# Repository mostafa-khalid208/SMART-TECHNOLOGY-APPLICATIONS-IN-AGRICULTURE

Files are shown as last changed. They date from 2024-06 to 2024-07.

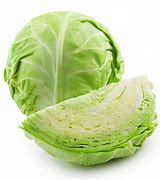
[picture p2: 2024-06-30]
APK & Code/smart_irrigation/smart_irrigation/assets/images/OIP_(1)ht.jpg

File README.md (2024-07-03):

# SMART-TECHNOLOGY-APPLICATIONS-IN-AGRICULTURE

Mobile application interface

In the ever-changing world of farming, smart agricultural systems have emerged as game-changers, using fancy tech to tackle big challenges like feeding a growing global population while being kind to the planet. This graduation project book is your go-to guide to understand and dive deep into these innovative farming solutions.

Create Login

Additional pages in the project

[Create & Login Account (Practical application ) ]( https://youtu.be/F7y6CJShDI8 )

We'll take you on a tour of the cool tech behind smart agriculture, from building mobile apps with Flutter to using AI for making smart decisions and managing data in the Cloud. You'll get hands-on with hardware like ESP32 and IoT devices, learning how they collect data and automate tasks on the farm.

Diagram_1

Diagram_2

Sensor reading page

[Sensors & Microcontroller ( Practical application ) ]( https://youtu.be/qTxyqkGCsHM )

But it's not all theory—get ready to roll up your sleeves and put these ideas into action. We'll show you how smart irrigation systems work, using sensors and AI to water crops just right. Plus, you'll learn how AI can spot plant diseases early, helping farmers protect their harvests and boost productivity.

Chat page with pictures with artificial intelligence

Chat page with artificial intelligence

[Artificial intelligence (AI) Chat & Image (Practical application ) ]( https://youtu.be/XoeHMlaQuq4 )

[Full in-app AI experience ]( https://youtube.com/shorts/PL40P1889J8 )

We won't just stop at building cool stuff; We'll also talk about how to measure success. We'll look at how these systems increase crop yields, save resources, and make farming more sustainable. And we'll dive into how they're making a real difference in food security and protecting our environment.

But we're not done yet—get ready to peer into the future of farming. We'll explore exciting new technology like 5G, fog computing, and the Internet of Everything, and how they'll shape the farms of tomorrow. And we'll discuss how renewable energy, virtual reality, and more will play a role in making farming even smarter.

FireBase(FireStore)

Solar System

[Firebase & FireStore (Practical application ) ]( https://youtu.be/0Hn9pTRTNbc )

By bringing together the latest research and hands-on practices, this project is your ticket to understanding and creating the future of farming. Whether you're a student looking to dive into smart agriculture or a researcher pushing the boundaries of what's possible, this project is your roadmap to a greener, more efficient future in farming.

the graduation project

[Smart Irrigation System (Final practical application of the graduation project ) ]( https://youtube.com/shorts/qQlA1rqxmsU?feature=shared )

[Full mobile app experience ]( https://youtu.be/DmjhwGzqkdA?feature=shared )

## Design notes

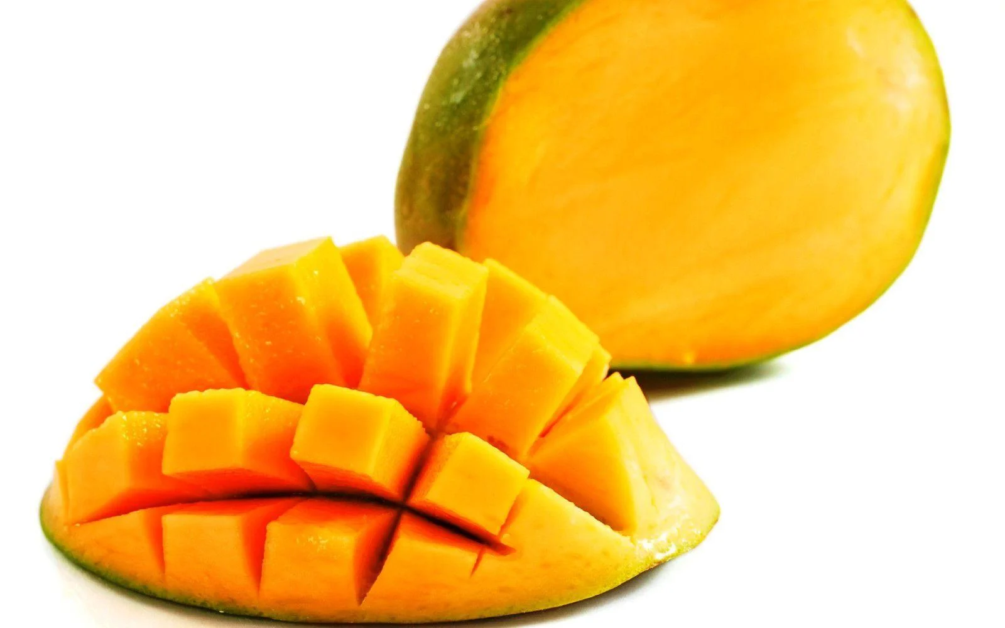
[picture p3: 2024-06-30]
APK & Code/smart_irrigation/smart_irrigation/assets/images/efef.webp

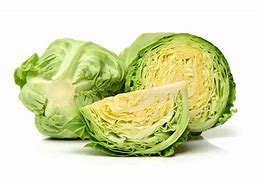
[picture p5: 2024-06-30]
APK & Code/smart_irrigation/smart_irrigation/assets/images/OIP_(1)gfg.jpg

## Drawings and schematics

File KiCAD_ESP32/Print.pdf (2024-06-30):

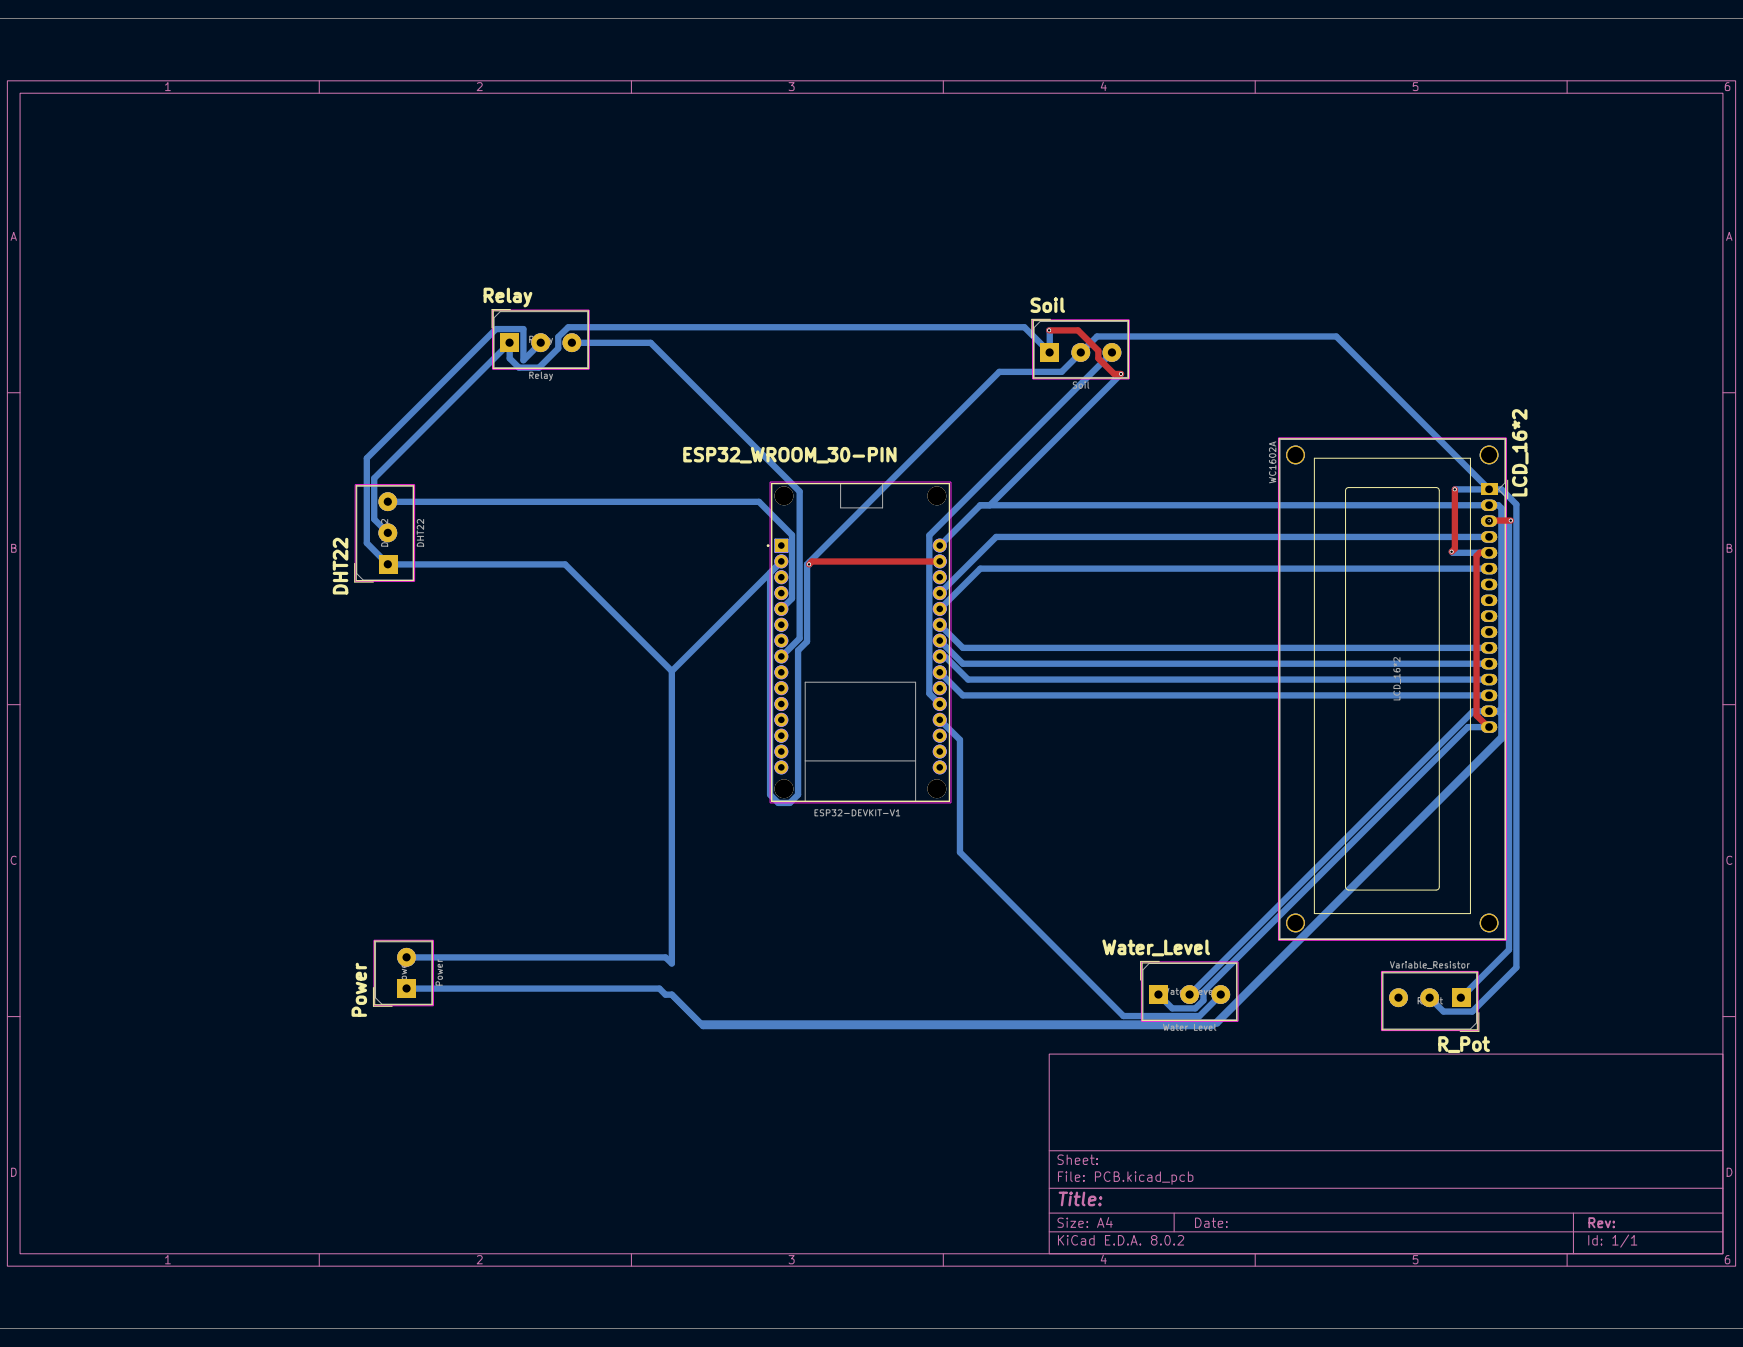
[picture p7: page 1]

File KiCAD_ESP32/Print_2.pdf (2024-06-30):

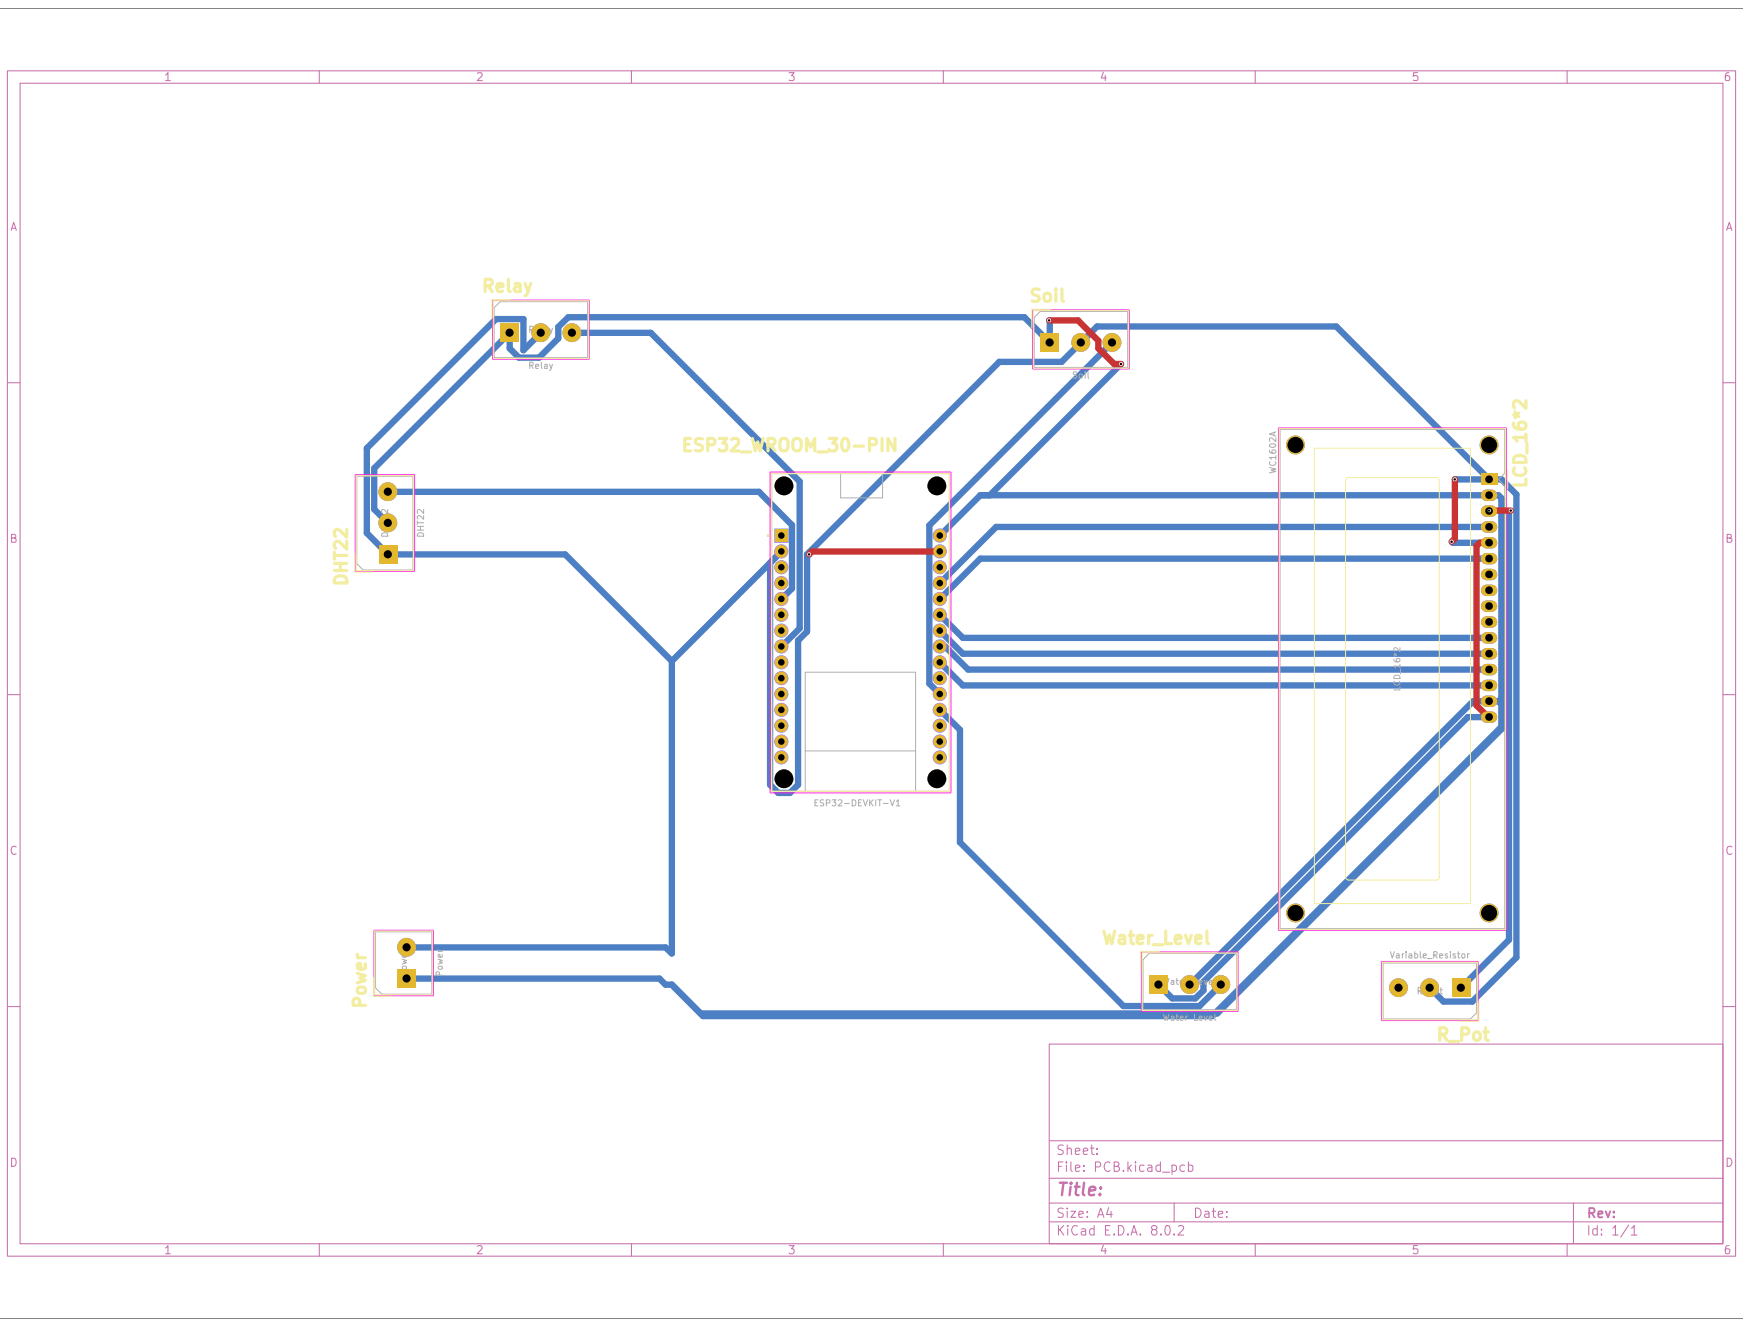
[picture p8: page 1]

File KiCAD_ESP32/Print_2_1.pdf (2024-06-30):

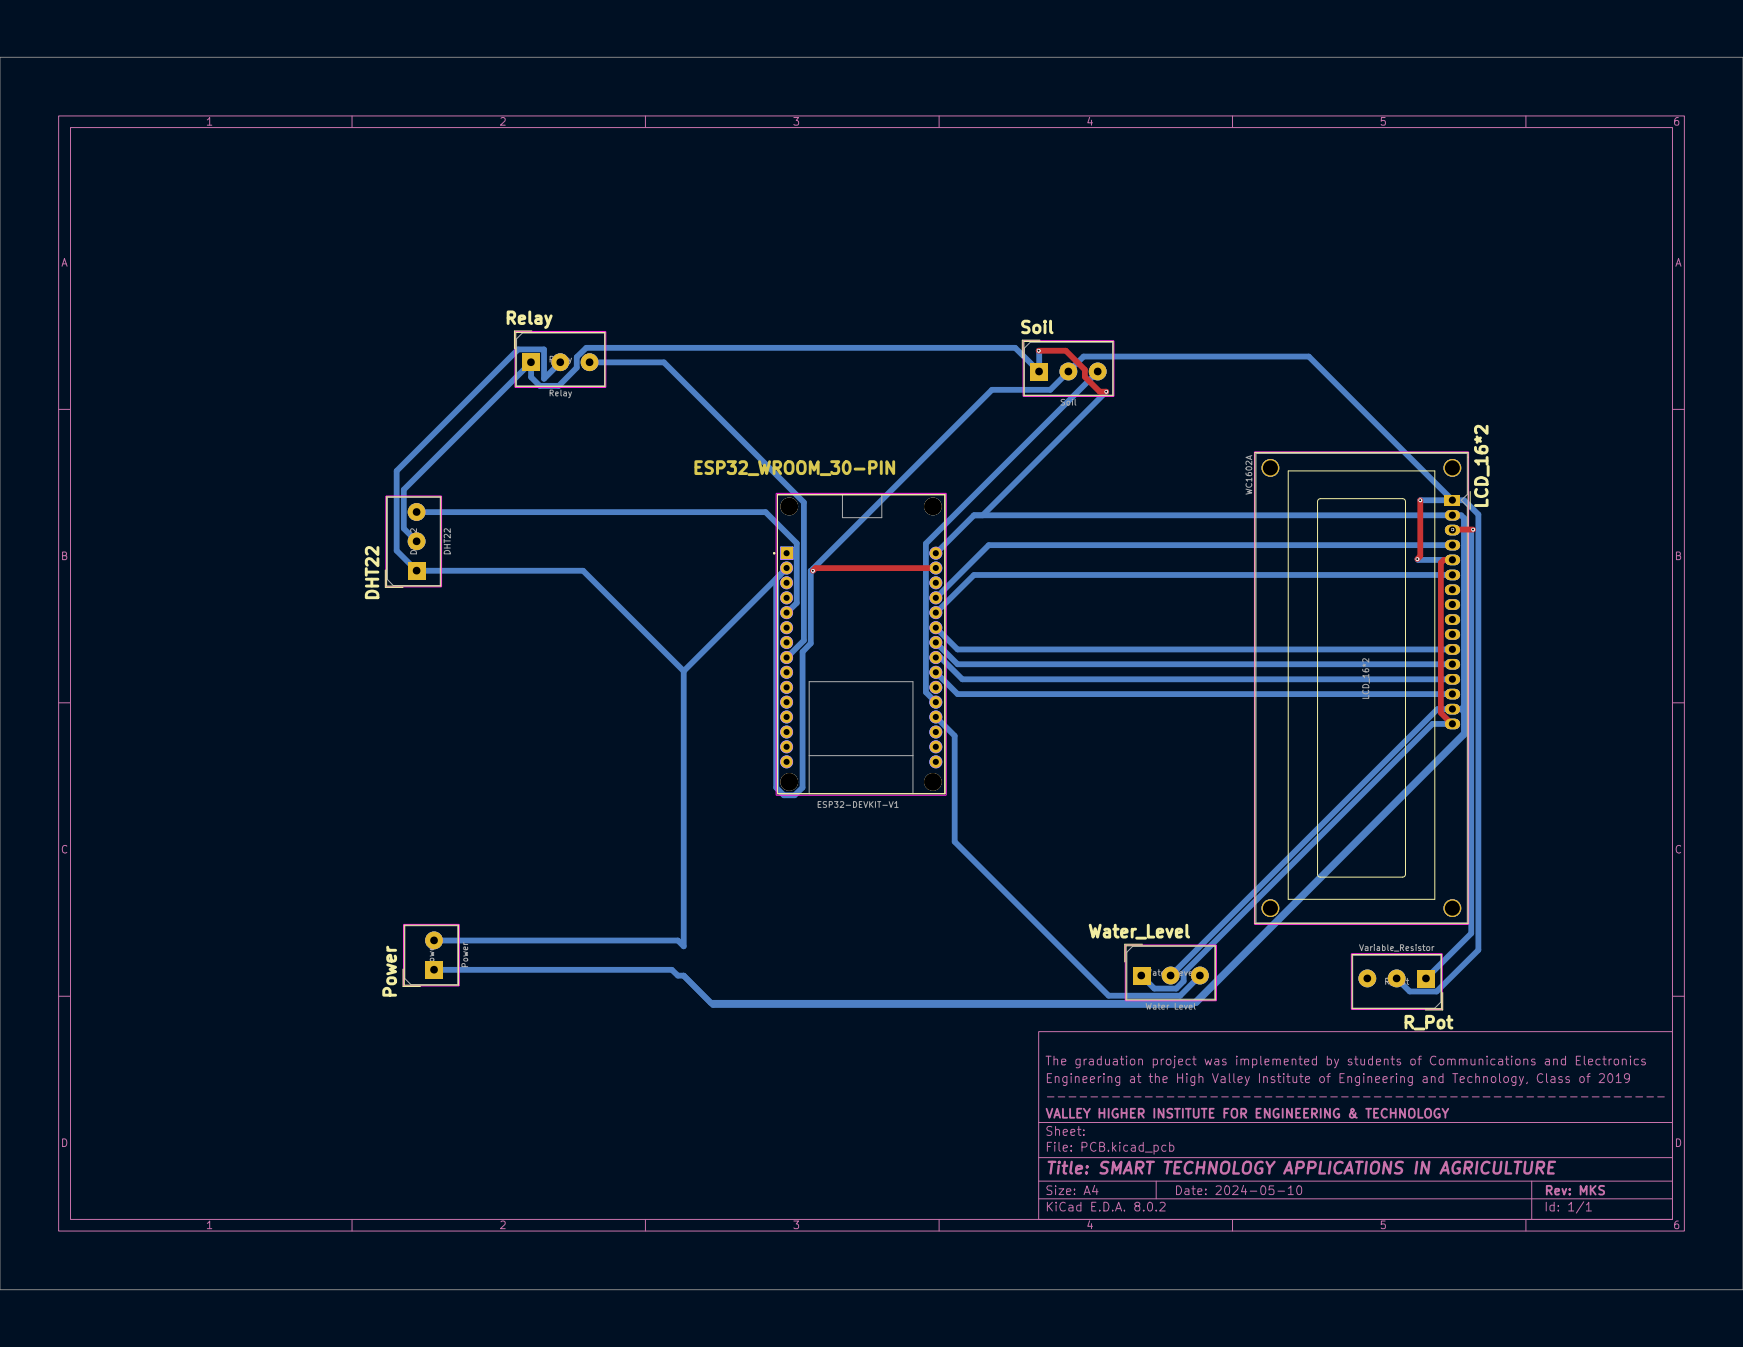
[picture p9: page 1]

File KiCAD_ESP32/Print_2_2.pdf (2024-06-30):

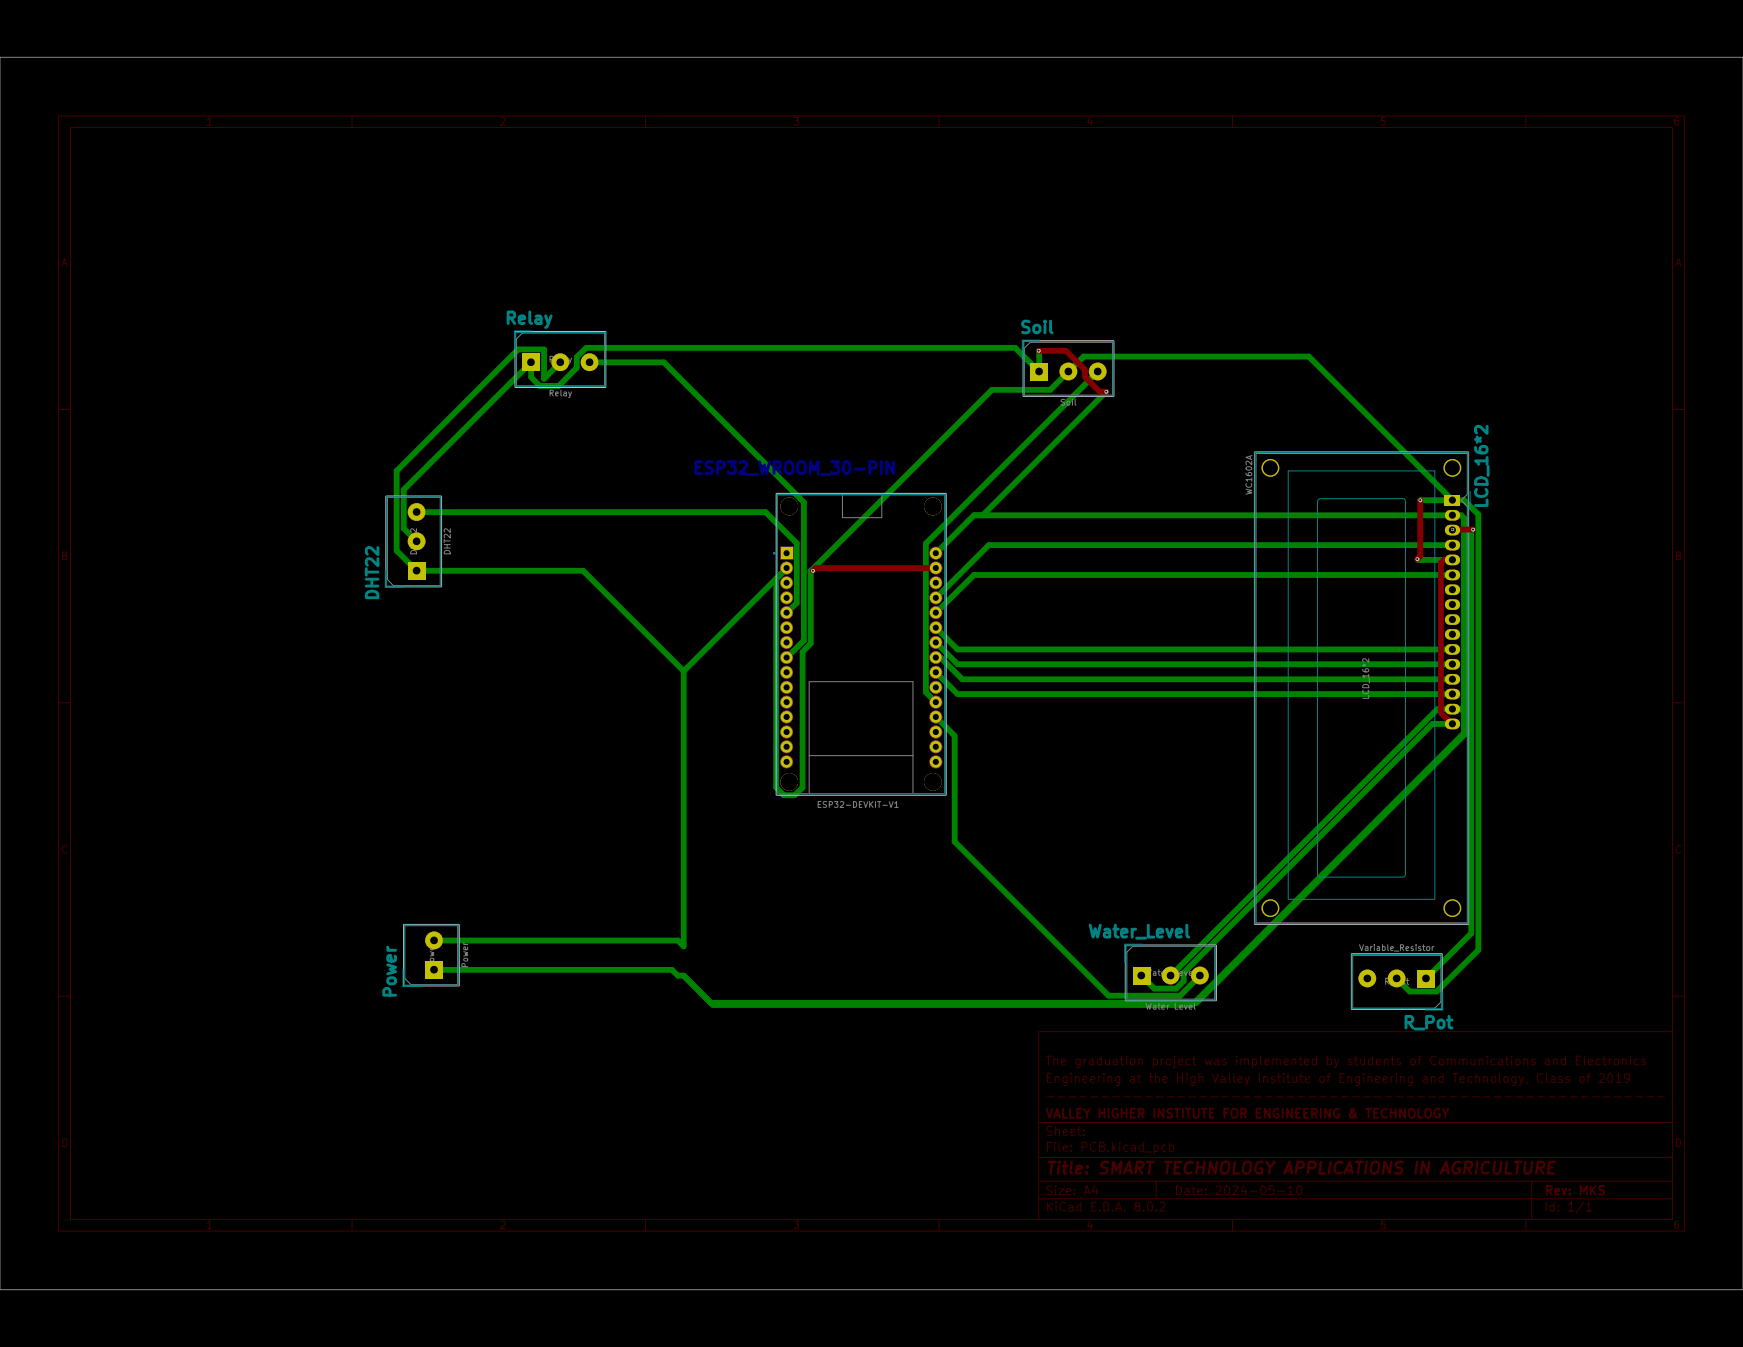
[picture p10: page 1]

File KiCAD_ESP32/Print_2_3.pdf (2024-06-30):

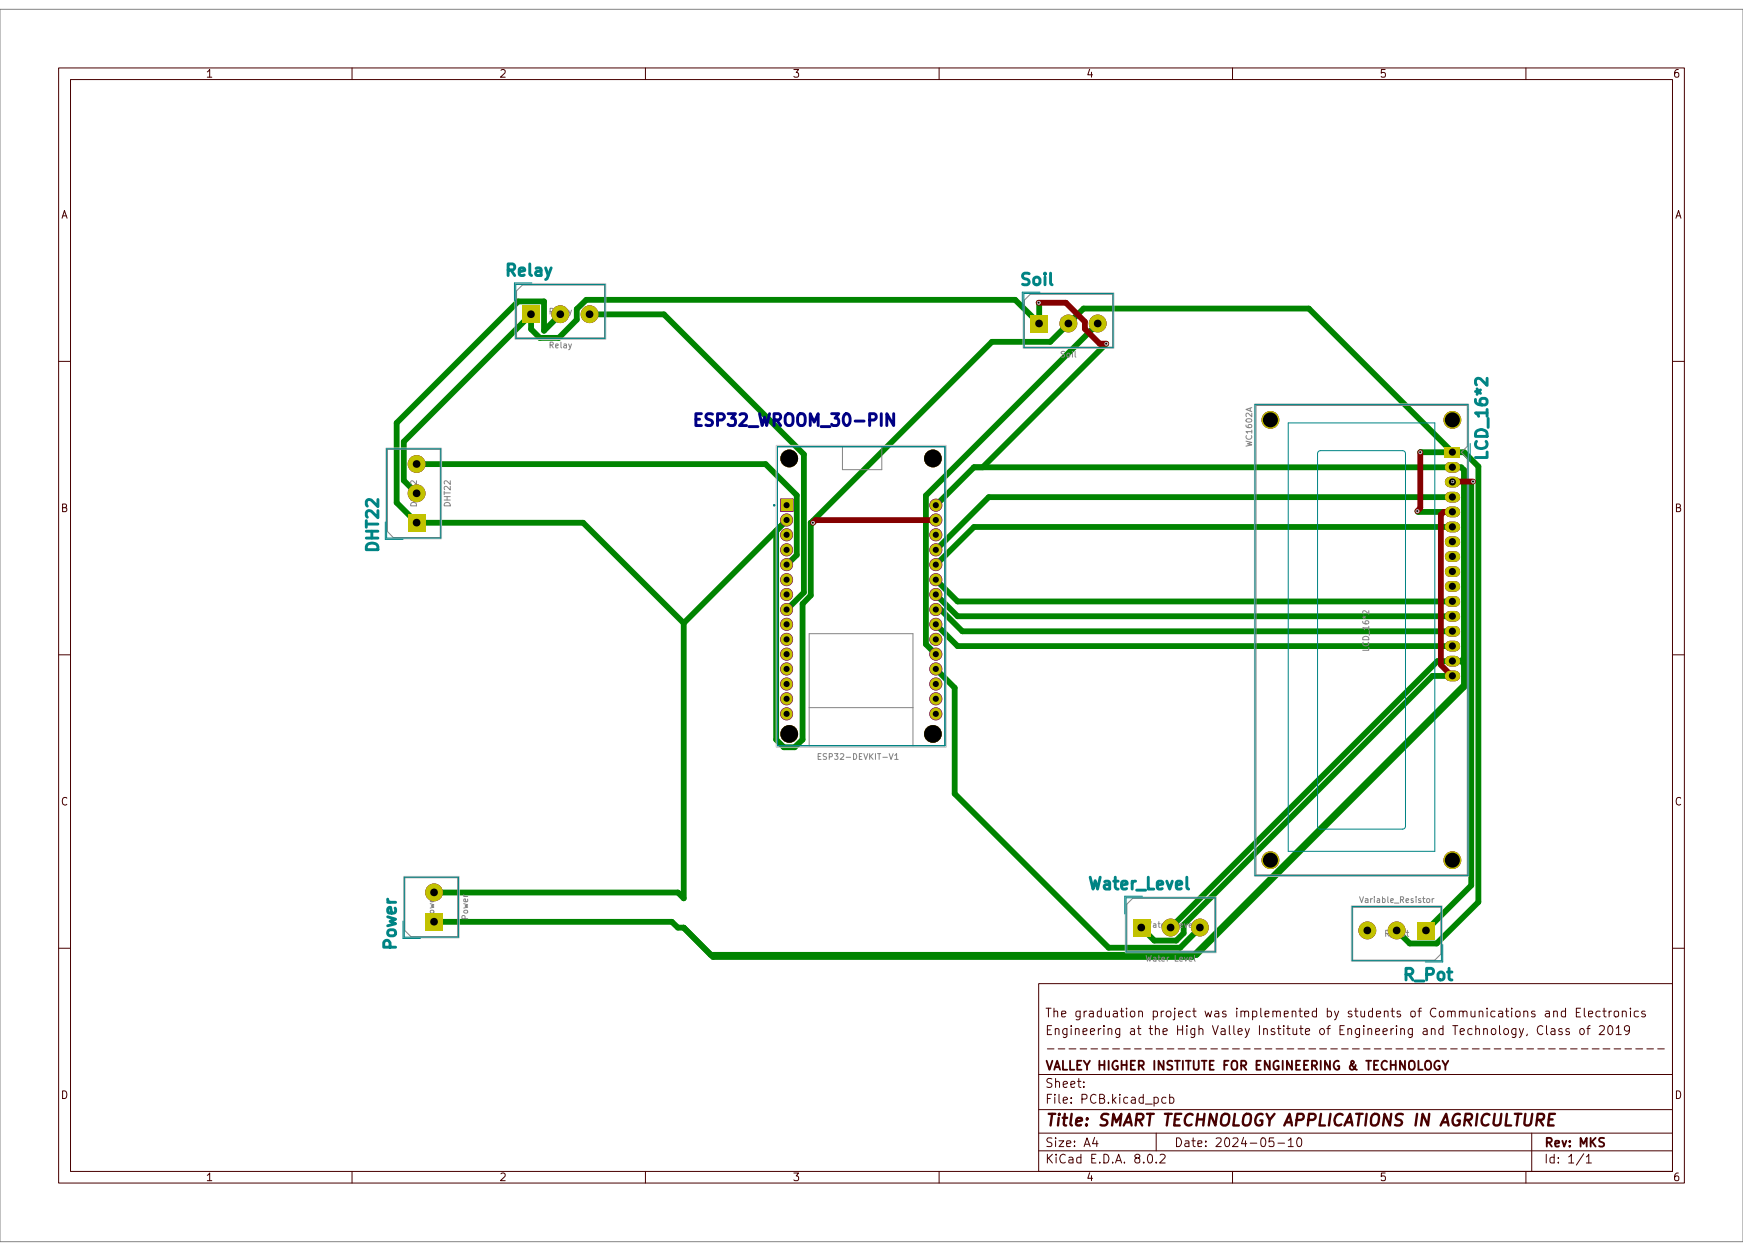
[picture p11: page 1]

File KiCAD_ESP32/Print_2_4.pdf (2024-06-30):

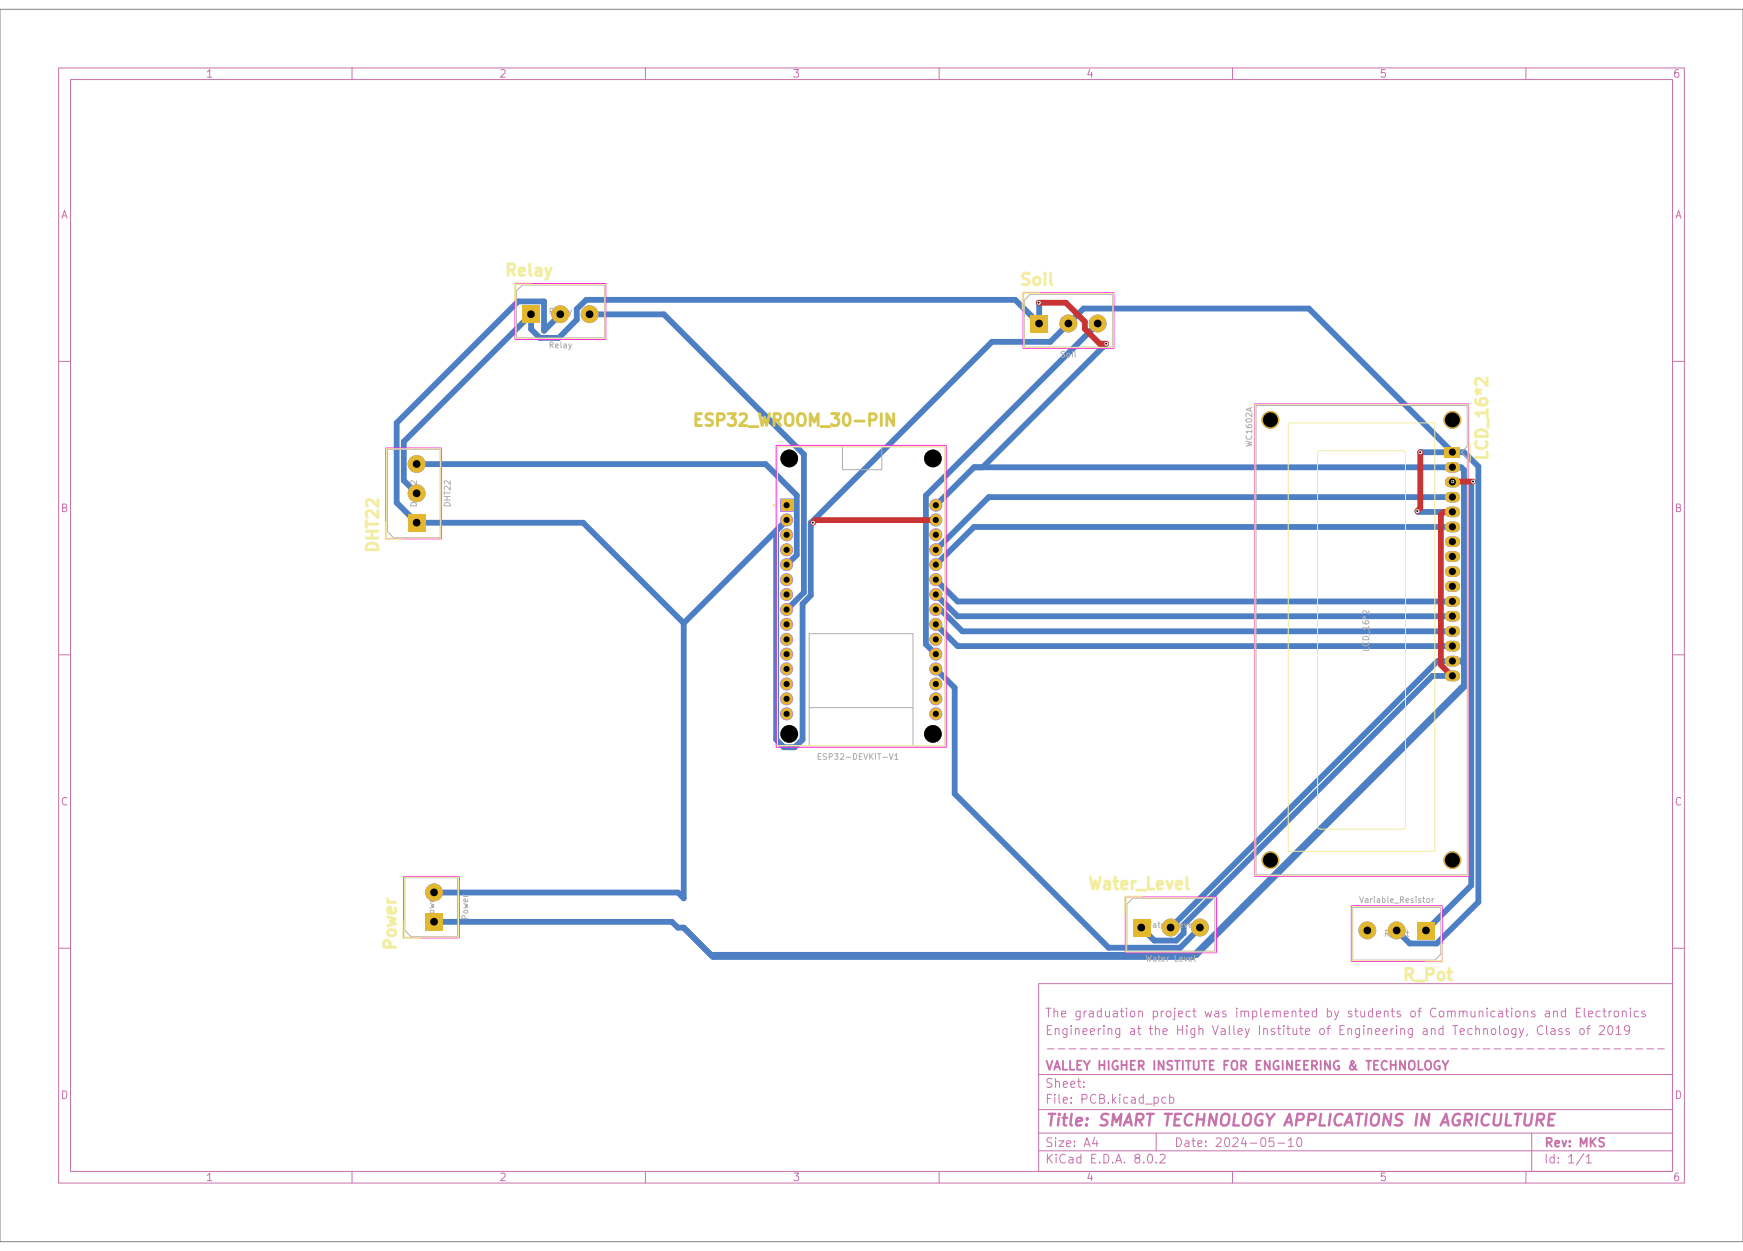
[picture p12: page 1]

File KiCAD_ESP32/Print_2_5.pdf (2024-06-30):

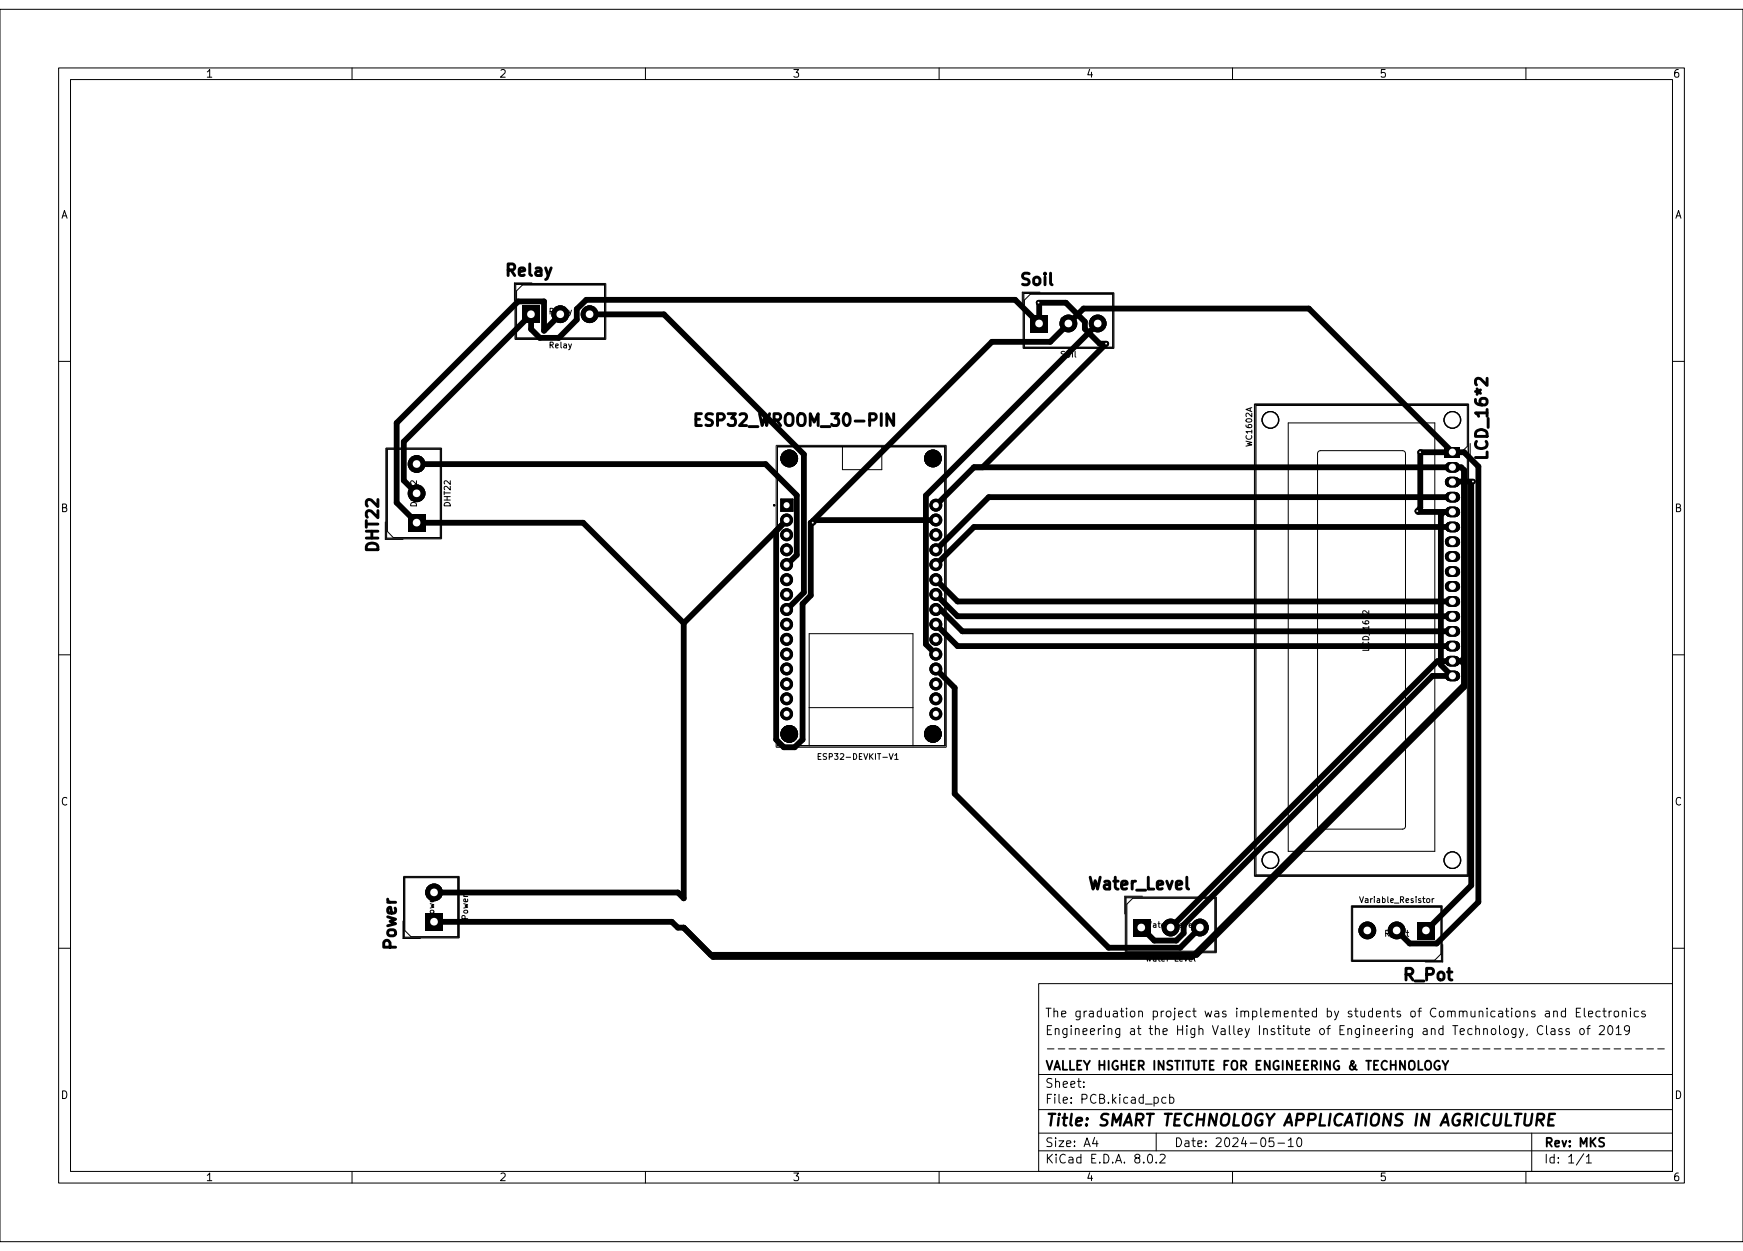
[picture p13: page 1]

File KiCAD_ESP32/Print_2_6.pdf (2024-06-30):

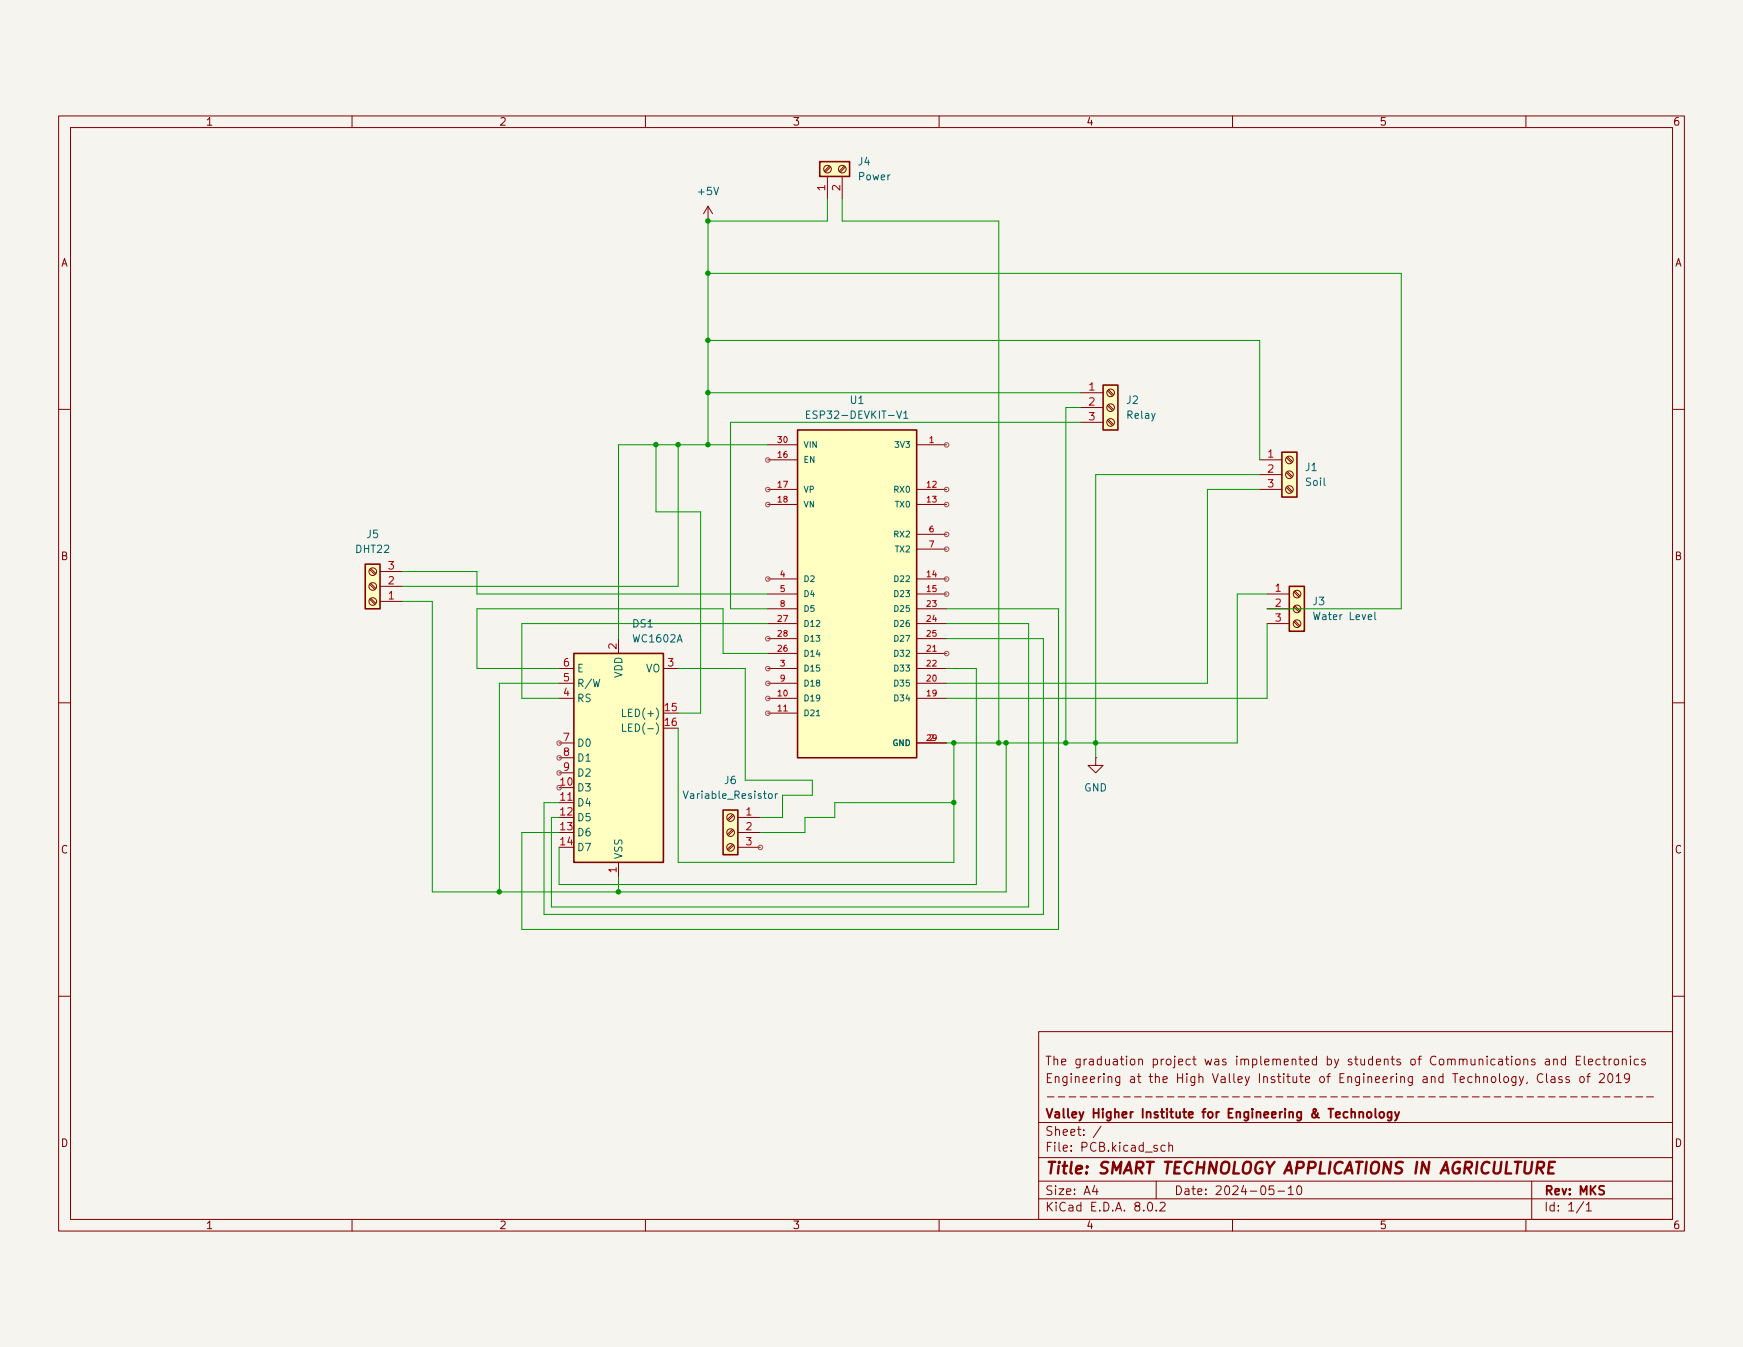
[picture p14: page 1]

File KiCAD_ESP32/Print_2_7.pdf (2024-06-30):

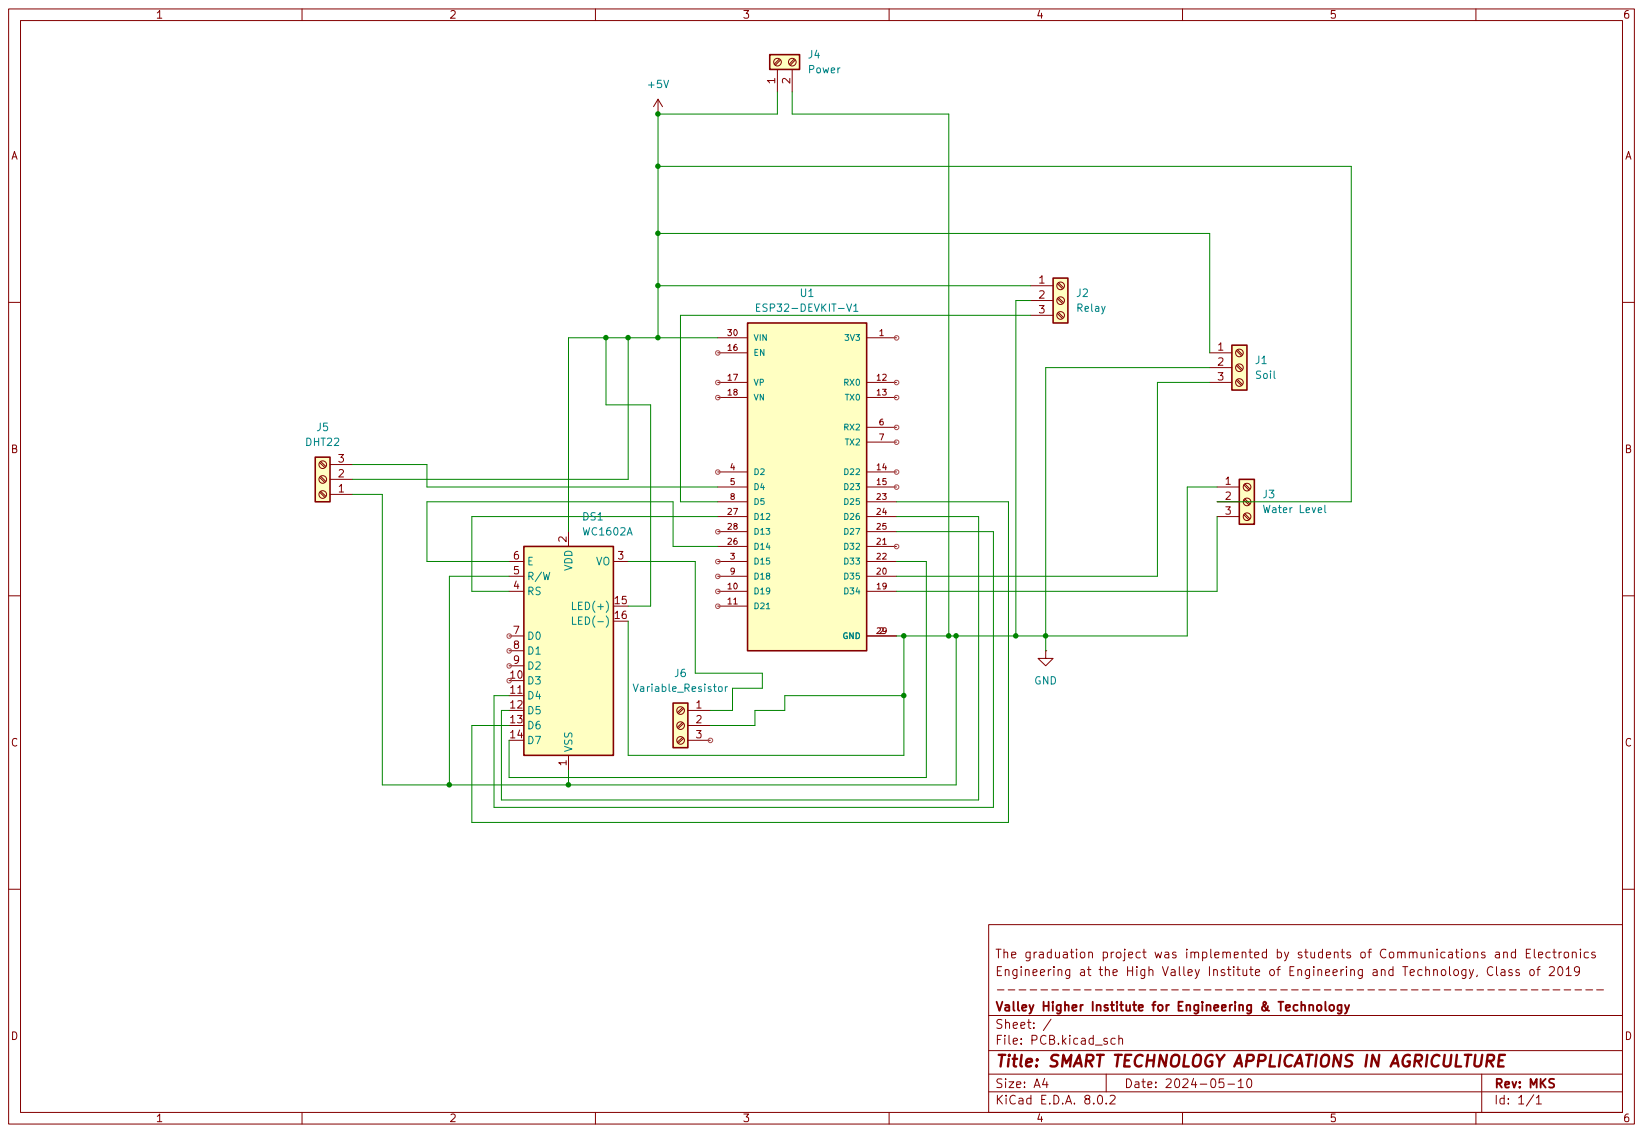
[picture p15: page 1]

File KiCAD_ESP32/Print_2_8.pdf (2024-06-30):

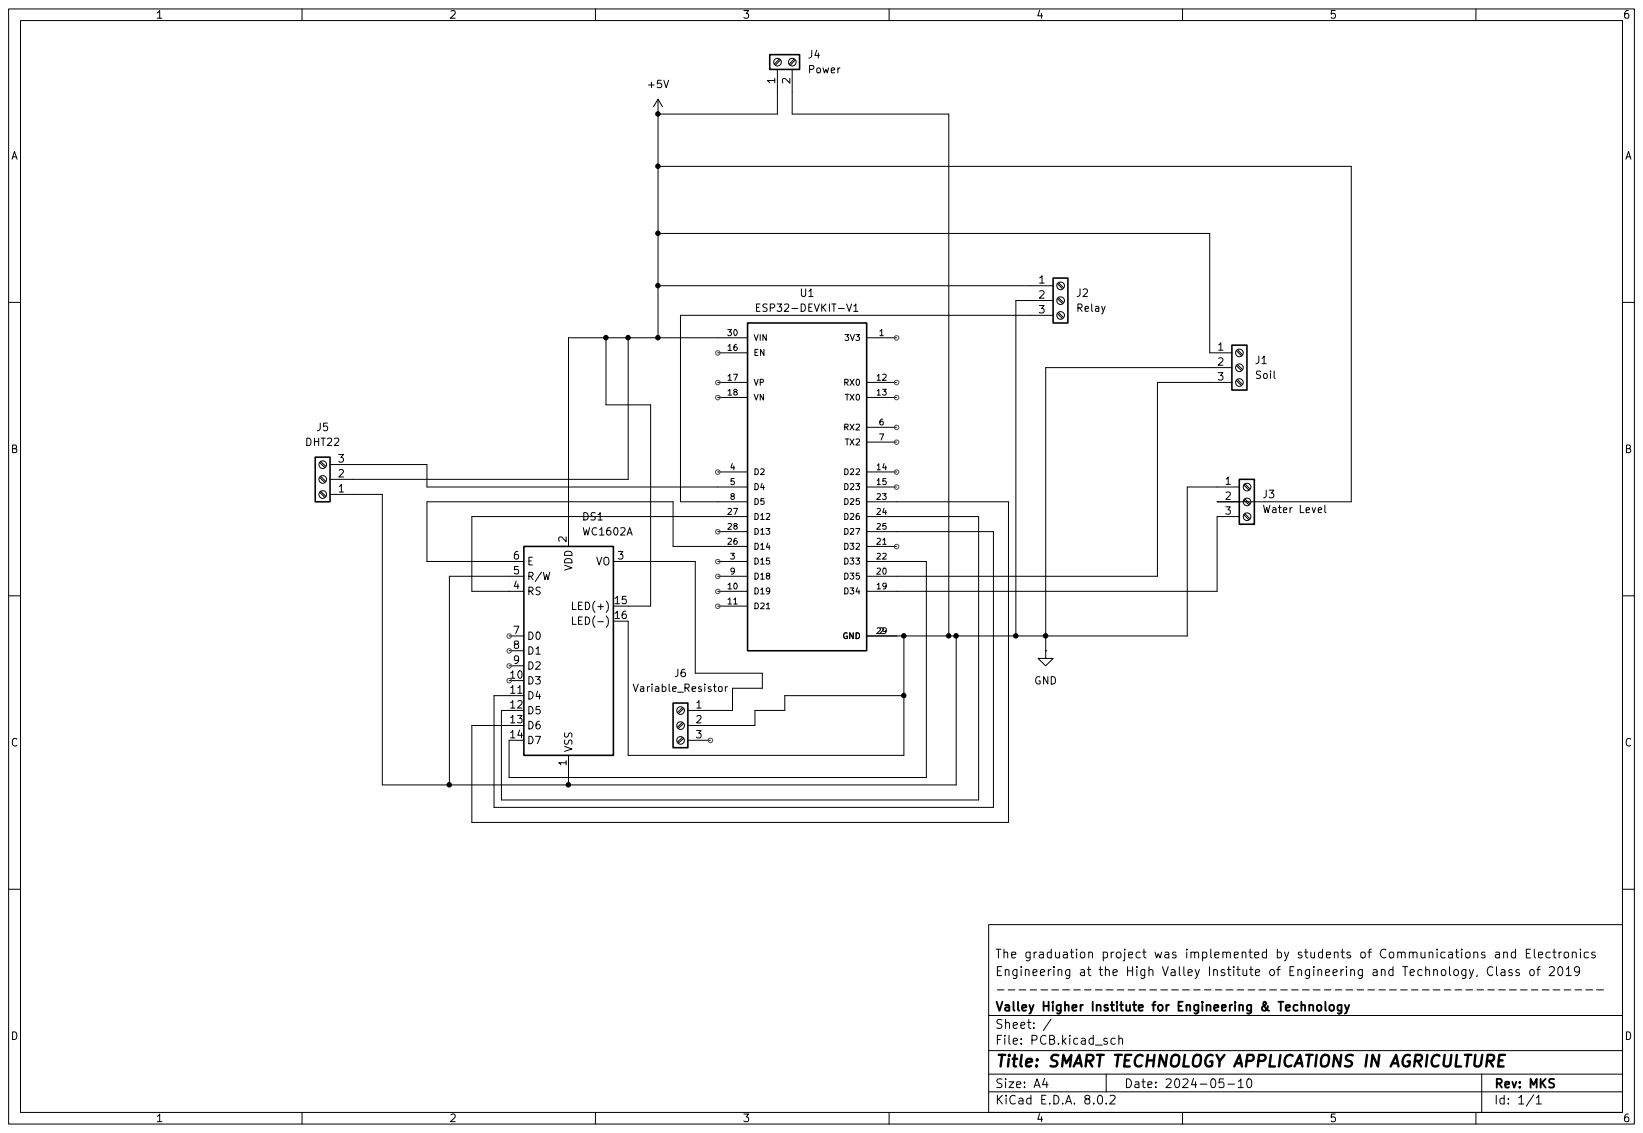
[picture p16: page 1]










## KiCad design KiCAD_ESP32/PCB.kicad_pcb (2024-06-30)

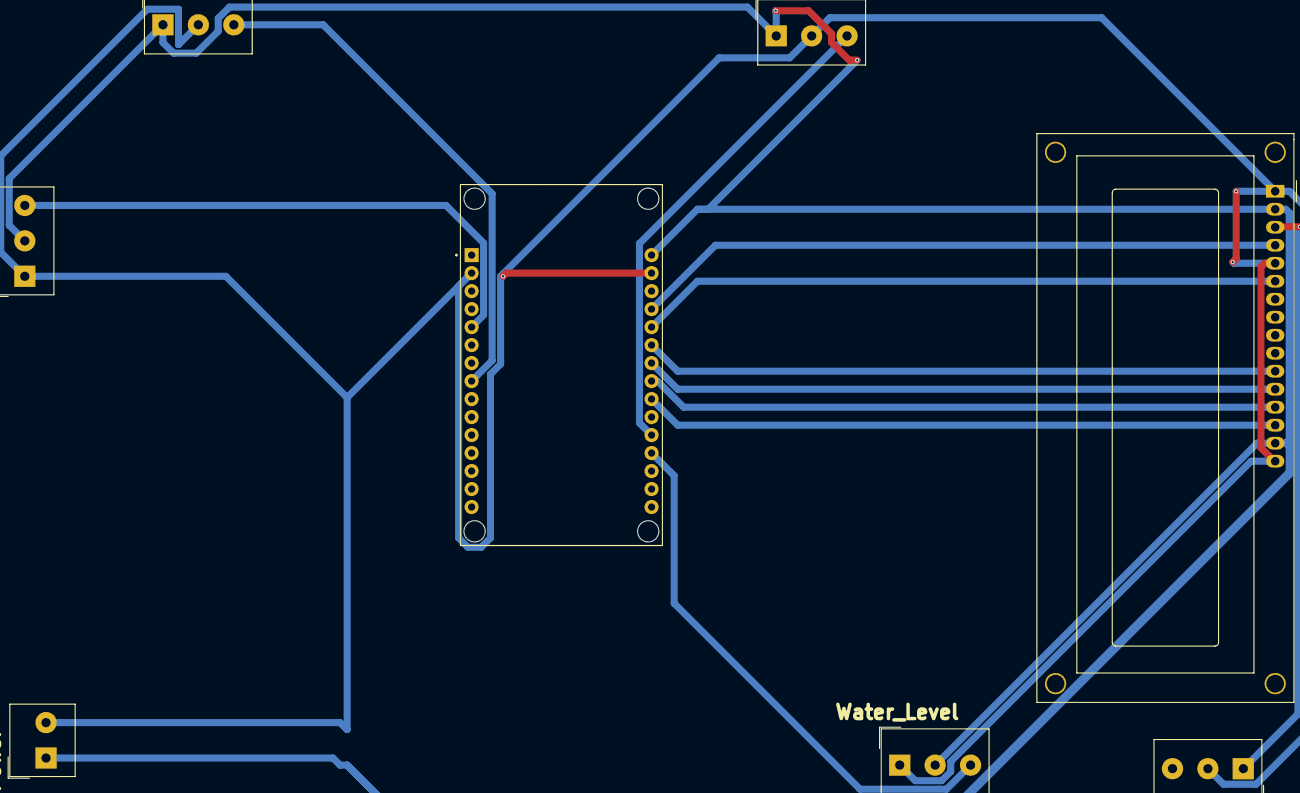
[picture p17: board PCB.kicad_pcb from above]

Board: 2 copper layers, 8 parts (0 on the bottom side), 13 nets.

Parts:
DHT22: DHT22; Altech_AK100_1x03_P5.00mm
ESP32_WROOM_30-PIN: ESP32-DEVKIT-V1; MODULE_ESP32_DEVKIT_V1
LCD_16*2: WC1602A
Power: Power; Altech_AK100_1x02_P5.00mm
R_Pot: Variable_Resistor; Altech_AK100_1x03_P5.00mm
Relay: Relay; Altech_AK100_1x03_P5.00mm
Soil: Soil; Altech_AK100_1x03_P5.00mm
Water_Level: Water Level; Altech_AK100_1x03_P5.00mm

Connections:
+5V: DHT22.2, ESP32_WROOM_30-PIN.30 (VIN), LCD_16*2.2 (VDD), LCD_16*2.15 (LED(+)), Power.1, Relay.1, Soil.1, Water_Level.2
GND: DHT22.1, ESP32_WROOM_30-PIN.2 (GND), ESP32_WROOM_30-PIN.29 (GND), LCD_16*2.1 (VSS), LCD_16*2.5 (R/W), LCD_16*2.16 (LED(-)), Power.2, R_Pot.2, Relay.2, Soil.2, Water_Level.1
unnamed: ESP32_WROOM_30-PIN.25 (D27), LCD_16*2.11 (D4)
unnamed: ESP32_WROOM_30-PIN.24 (D26), LCD_16*2.12 (D5)
unnamed: ESP32_WROOM_30-PIN.23 (D25), LCD_16*2.13 (D6)
unnamed: ESP32_WROOM_30-PIN.22 (D33), LCD_16*2.14 (D7)
unnamed: ESP32_WROOM_30-PIN.26 (D14), LCD_16*2.6 (E)
unnamed: ESP32_WROOM_30-PIN.27 (D12), LCD_16*2.4 (RS)
unnamed: LCD_16*2.3 (VO), R_Pot.1
unnamed: ESP32_WROOM_30-PIN.20 (D35), Soil.3
unnamed: ESP32_WROOM_30-PIN.8 (D5), Relay.3
unnamed: ESP32_WROOM_30-PIN.19 (D34), Water_Level.3
unnamed: DHT22.3, ESP32_WROOM_30-PIN.5 (D4)

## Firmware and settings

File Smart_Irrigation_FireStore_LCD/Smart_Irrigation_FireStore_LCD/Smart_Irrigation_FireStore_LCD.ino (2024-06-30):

#define BLYNK_TEMPLATE_ID "Replace your BLYNK_TEMPLATE_ID here"
#define BLYNK_TEMPLATE_NAME "Replace your BLYNK_TEMPLATE_NAME here"
#define BLYNK_AUTH_TOKEN "Replace your BLYNK_AUTH_TOKEN here"
#define BLYNK_PRINT Serial
#define FIREBASE_PROJECT_ID "smart-irrigation-v77nzz"

#include <WiFi.h>
#include <BlynkSimpleEsp32.h>
#include "DHT.h"
#include <FastLED.h>
#include <Arduino.h>
#include <Firebase_ESP_Client.h>
#include <LiquidCrystal.h>  // Include the library for LCD display

FirebaseAuth firebaseAuth;
FirebaseConfig firebaseConfig;
FirebaseData firebaseData;

char auth[] = BLYNK_AUTH_TOKEN;
const char *ssid = "T(-E-)G"; // Wifi network name.
const char *pass = "*T1972023-E-1SMT'";

#define LED_PIN 21
#define BRIGHTNESS 255
#define LED_TYPE WS2811
#define COLOR_ORDER GRB

const uint8_t kMatrixWidth = 16;
const uint8_t kMatrixHeight = 16;
const bool kMatrixSerpentineLayout = true;

#define NUM_LEDS (kMatrixWidth * kMatrixHeight)
#define MAX_DIMENSION ((kMatrixWidth > kMatrixHeight) ? kMatrixWidth : kMatrixHeight)

// The leds
CRGB leds[kMatrixWidth * kMatrixHeight];
BlynkTimer timer;
bool ledStripOn = false;
// The 16 bit version of our coordinates
static uint16_t x;
static uint16_t y;
static uint16_t z;


uint16_t speed = 20;  // speed is set dynamically once we've started up
uint16_t scale = 30;  // scale is set dynamically once we've started up
uint8_t noise[MAX_DIMENSION][MAX_DIMENSION];

CRGBPalette16 currentPalette(PartyColors_p);
uint8_t colorLoop = 1;

#define DHTPIN 4
#define DHTTYPE DHT22

DHT dht(DHTPIN, DHTTYPE);
const int soilMoisturePin = 35;  // Analog pin for the soil moisture sensor
const int waterLevelPin = 34;    // Analog pin for the water level sensor
const int ledPin = 2;

// Constants for soil moisture thresholds
const int SOIL_MOISTURE_LOW = 50;   // Adjusted to match the 0-100 range
const int SOIL_MOISTURE_HIGH = 50;  // Adjusted to match the 0-100 range

const int pumpPin = 5;  // Change this to the actual pin connected to the DC pump on ESP32
int pumpState = LOW;    // Initialize pumpState to LOW (off)
int pumpMode = 0;       // 0 for automatic, 1 for manual

int waterLevel = 0;  // Water level indicator value
unsigned long previousMillis = 0;
const unsigned long interval = 1000;  // Interval in milliseconds

float mappedSoilMoisture = 0;  // Declare mappedSoilMoisture as a global variable

// Initialize the LCD object with the appropriate pins
const int rs = 25, en = 33, d4 = 12, d5 = 14, d6 = 27, d7 = 26, rw = 32; // Define RW pin
LiquidCrystal lcd(rs, rw, en, d4, d5, d6, d7); // Initialize LCD with RW pin

void setup() {
  Serial.begin(115200);
  Serial.print("Connecting With");
  Serial.println(ssid);
  WiFi.begin(ssid, pass);
  while (WiFi.status() != WL_CONNECTED) {
    delay(500);
    Serial.print(".");
  }
  Serial.println("");
  Serial.print("WiFi connected. IP:");
  Serial.println(WiFi.localIP());

  firebaseConfig.signer.test_mode = true;

  Firebase.reconnectWiFi(true);
  Firebase.begin(&firebaseConfig, &firebaseAuth);

  digitalWrite(pumpPin, LOW);
  pinMode(ledPin, OUTPUT);
  pinMode(pumpPin, OUTPUT);
  dht.begin();
  Blynk.begin(auth, ssid, pass);
  Blynk.virtualWrite(V2, LOW);
  Blynk.virtualWrite(V3, "LED OFF");
  Blynk.virtualWrite(V6, LOW);  // Initialize the mode button to automatic mode
  Blynk.virtualWrite(V5, LOW);  // Initialize the pump button to OFF
  Blynk.virtualWrite(V8, LOW);  // Initialize the new feature button to OFF
  delay(3000);
  LEDS.addLeds<LED_TYPE, LED_PIN, COLOR_ORDER>(leds, 80);
  LEDS.setBrightness(BRIGHTNESS);

  // Initialize our coordinates to some random values
  x = random16();
  y = random16();
  z = random16();

  // Initialize the LCD
  lcd.begin(16, 2);
}

BLYNK_WRITE(V5) {                      // This function is called when the pump button state changes (Manual Control)
  if (pumpMode == 1) {                 // Check if the mode is manual
    pumpState = param.asInt();         // Read the state of the pump button (0 for OFF, 1 for ON)
    digitalWrite(pumpPin, pumpState);  // Turn the pump on or off based on button state
  }
}

BLYNK_WRITE(V6) {            // This function is called when the mode button state changes
  pumpMode = param.asInt();  // Read the state of the mode button (0 for automatic, 1 for manual)
}

BLYNK_WRITE(V8) {
  int value = param.asInt();
  if (value == 1) {
    // Turn on the LED strip and start the animation
    ledStripOn = true;
  } else {
    // Turn off the LED strip
    ledStripOn = false;
    // You can also add code to clear the LED strip here if needed
  }
}

// Fill the x/y array of 8-bit noise values using the inoise8 function.
void fillnoise8() {
  // If we're runing at a low "speed", some 8-bit artifacts become visible
  // from frame-to-frame.  In order to reduce this, we can do some fast data-smoothing.
  // The amount of data smoothing we're doing depends on "speed".
  uint8_t dataSmoothing = 0;
  if (speed < 50) {
    dataSmoothing = 200 - (speed * 4);
  }

  for (int i = 0; i < MAX_DIMENSION; i++) {
    int ioffset = scale * i;
    for (int j = 0; j < MAX_DIMENSION; j++) {
      int joffset = scale * j;

      uint8_t data = inoise8(x + ioffset, y + joffset, z);

      // The range of the inoise8 function is roughly 16-238.
      // These two operations expand those values out to roughly 0..255
      // You can comment them out if you want the raw noise data.
      data = qsub8(data, 16);
      data = qadd8(data, scale8(data, 39));

      if (dataSmoothing) {
        uint8_t olddata = noise[i][j];
        uint8_t newdata = scale8(olddata, dataSmoothing) + scale8(data, 256 - dataSmoothing);
        data = newdata;
      }

      noise[i][j] = data;
    }
  }

  z += speed;

  // apply slow drift to X and Y, just for visual variation.
  x += speed / 8;
  y -= speed / 16;
}

void mapNoiseToLEDsUsingPalette() {
  static uint8_t ihue = 0;

  for (int i = 0; i < kMatrixWidth; i++) {
    for (int j = 0; j < kMatrixHeight; j++) {
      // We use the value at the (i,j) coordinate in the noise
      // array for our brightness, and the flipped value from (j,i)
      // for our pixel's index into the color palette.

      uint8_t index = noise[j][i];
      uint8_t bri = noise[i][j];

      // if this palette is a 'loop', add a slowly-changing base value
      if (colorLoop) {
        index += ihue;
      }

      // brighten up, as the color palette itself often contains the
      // light/dark dynamic range desired
      if (bri > 127) {
        bri = 255;
      } else {
        bri = dim8_raw(bri * 2);
      }

      CRGB color = ColorFromPalette(currentPalette, index, bri);
      leds[XY(i, j)] = color;
    }
  }

  ihue += 1;
}

void loop() {
  Blynk.run();
  timer.run();

  updateLEDStrip();
  unsigned long currentMillis = millis();

  if (currentMillis - previousMillis >= interval) {
    previousMillis = currentMillis;

    // Read soil moisture or water level based on the flag
    if (pumpMode == 0) {
      int soilSensorValue = analogRead(soilMoisturePin);
      Serial.println(soilSensorValue);
      mappedSoilMoisture = map(soilSensorValue, 1023, 2750, 100, 0);  // Update mappedSoilMoisture
  
      autoControlPump(mappedSoilMoisture);                            // Automatically control the pump based on soil moisture if in automatic mode
    }

    // Read water level
    waterLevel = analogRead(waterLevelPin);
    Serial.println(waterLevel);
    if (waterLevel < 450) {
      waterLevel = 0;  // Set water level to 0 if below a threshold
    } else {
      waterLevel = map(waterLevel, 1200, 1600, 0, 100);  // Map water level to 0-100
    }

    

    // Control LED
    controlLED(mappedSoilMoisture);

    // Read and send sensor data
    readAndSendSensorData();

    Blynk.virtualWrite(V7, waterLevel);  // Send water level to Blynk

    // Display sensor readings on LCD
    displaySensorReadingsOnLCD(); //(double mappedSoilMoisture, double waterLevel);
  }
}

void displaySensorReadingsOnLCD() {
  lcd.clear();
  
  lcd.setCursor(0, 0);
  lcd.print("Temp: ");
  lcd.print(dht.readTemperature());
  lcd.print(" C");
  delay(2500);

  lcd.setCursor(0, 1); // تحريك المؤشر للصف الثاني
  lcd.print("Humidity: ");
  lcd.print(dht.readHumidity());
  lcd.print(" %");
  delay(2500);

  lcd.setCursor(0, 0); // تحريك المؤشر للصف الأول مرة أخرى
  lcd.print("Soil: ");
  lcd.print(mappedSoilMoisture);
  lcd.print(" %");
  delay(2500);

  lcd.setCursor(0, 1); // تحريك المؤشر للصف الثاني مرة أخرى
  lcd.print("Wat.Lev: ");
  lcd.print(waterLevel);
  lcd.print(" %");
  delay(2500);
}

void autoControlPump(float mappedSoilMoisture) {
  if (waterLevel < 30 || waterLevel < 20) {
    // Water level is too low, do not turn on the pump
    pumpState = LOW;
    digitalWrite(ledPin, LOW);
    Blynk.virtualWrite(V2, HIGH);
    Blynk.setProperty(V2, "color", "#D3435C");

  } else if (mappedSoilMoisture <= SOIL_MOISTURE_LOW) {
    // If soil moisture is below the threshold and water level is okay, turn the pump ON
    pumpState = HIGH;
  } else if (mappedSoilMoisture >= SOIL_MOISTURE_HIGH) {
    // If soil moisture is above the threshold, turn the pump OFF
    pumpState = LOW;
  }

  digitalWrite(pumpPin, pumpState);  // Update the pump state
  if (pumpMode == 0) {
    Blynk.virtualWrite(V5, pumpState);  // Update the pump button status on Blynk
  }
}

void controlLED(float mappedSoilMoisture) {
  if (mappedSoilMoisture <= SOIL_MOISTURE_LOW) {
    digitalWrite(ledPin, HIGH);
    Blynk.virtualWrite(V2, HIGH);
    Blynk.setProperty(V2, "color", "#00FF00");
    Blynk.virtualWrite(V3, "LED ON");
    Blynk.setProperty(V3, "color", "#00FF00");
  } else if (mappedSoilMoisture >= SOIL_MOISTURE_HIGH) {
    digitalWrite(ledPin, LOW);
    Blynk.virtualWrite(V2, HIGH);
    Blynk.setProperty(V2, "color", "#D3435C");
    Blynk.virtualWrite(V3, "LED OFF");
    Blynk.setProperty(V3, "color", "#D3435C");
  }
}

void readAndSendSensorData() {
  float humidity = dht.readHumidity();
  float temperature = dht.readTemperature();

  if (!isnan(humidity) && !isnan(temperature)) {
    Blynk.virtualWrite(V0, temperature);
    Blynk.virtualWrite(V1, humidity);
    Serial.println(temperature);
    Serial.println(humidity);
  } else {
    Serial.println(F("Failed to read from DHT sensor!"));
  }

  if (pumpMode == 0) {
    Blynk.virtualWrite(V4, mappedSoilMoisture);  // Update mappedSoilMoisture on Blynk
  }

  updateFirebase(temperature, humidity);
}

void updateFirebase(float temperature, float humidity) {
  // booleanValue, doubleValue, integerValue, stringValue
  FirebaseJson content;
  String documentPath = "sensors/esp32";  // This collection/document must exist in firestore in order for `patchDocument` to work.
  content.clear();
  content.set("fields/temperature/doubleValue", temperature);
  content.set("fields/humidity/doubleValue", humidity);
  content.set("fields/soil_moisture/doubleValue", mappedSoilMoisture);
  content.set("fields/water_level/integerValue", waterLevel);
  content.set("fields/ledPin/integerValue", ledPin);
  content.set("fields/pumpState/integerValue", pumpState);
  content.set("fields/ledStripState/booleanValue", ledStripOn);

  if (Firebase.Firestore.patchDocument(&firebaseData, FIREBASE_PROJECT_ID, "(default)", documentPath.c_str(), content.raw(), "", "", "true")) {
    Serial.printf("ok\n%s\n\n", firebaseData.payload().c_str());
  } else {
    Serial.println(firebaseData.errorReason());
  }
}

void updateLEDStrip() {
  if (ledStripOn) {
    // Your LED strip animation code here
    // This code will run when the LED strip is turned on
    // Make sure to update the leds array
    // For example, mapNoiseToLEDsUsingPalette();
    ChangePaletteAndSettingsPeriodically();
    fillnoise8();                  // Call the noise generation function
    mapNoiseToLEDsUsingPalette();  // Map the noise data to LEDs
    LEDS.show();                   // Show the LEDs
    // You may need to adjust the animation speed based on your preference
    delay(10);  // Delay between frames (adjust as needed)
  } else {
    // Turn off the LED strip
    // You can also add code to clear the LED strip here if needed
    fill_solid(leds, NUM_LEDS, CRGB::Black);
    LEDS.show();
  }
}
// There are several different palettes of colors demonstrated here.
//
// FastLED provides several 'preset' palettes: RainbowColors_p, RainbowStripeColors_p,
// OceanColors_p, CloudColors_p, LavaColors_p, ForestColors_p, and PartyColors_p.
//
// Additionally, you can manually define your own color palettes, or you can write
// code that creates color palettes on the fly.

// 1 = 5 sec per palette
// 2 = 10 sec per palette
// etc
#define HOLD_PALETTES_X_TIMES_AS_LONG 1

void ChangePaletteAndSettingsPeriodically() {
  uint8_t secondHand = ((millis() / 1000) / HOLD_PALETTES_X_TIMES_AS_LONG) % 60;
  static uint8_t lastSecond = 99;

  if (lastSecond != secondHand) {
    lastSecond = secondHand;
    if (secondHand == 0) {
      currentPalette = RainbowColors_p;
      speed = 20;
      scale = 30;
      colorLoop = 1;
    }
    if (secondHand == 5) {
      SetupPurpleAndGreenPalette();
      speed = 10;
      scale = 50;
      colorLoop = 1;
    }
    if (secondHand == 10) {
      SetupBlackAndWhiteStripedPalette();
      speed = 20;
      scale = 30;
      colorLoop = 1;
    }
    if (secondHand == 15) {
      currentPalette = ForestColors_p;
      speed = 8;
      scale = 120;
      colorLoop = 0;
    }
    if (secondHand == 20) {
      currentPalette = CloudColors_p;
      speed = 4;
      scale = 30;
      colorLoop = 0;
    }
    if (secondHand == 25) {
      currentPalette = LavaColors_p;
      speed = 8;
      scale = 50;
      colorLoop = 0;
    }
    if (secondHand == 30) {
      currentPalette = OceanColors_p;
      speed = 20;
      scale = 90;
      colorLoop = 0;
    }
    if (secondHand == 35) {
      currentPalette = PartyColors_p;
      speed = 20;
      scale = 30;
      colorLoop = 1;
    }
    if (secondHand == 40) {
      SetupRandomPalette();
      speed = 20;
      scale = 20;
      colorLoop = 1;
    }
    if (secondHand == 45) {
      SetupRandomPalette();
      speed = 50;
      scale = 50;
      colorLoop = 1;
    }
    if (secondHand == 50) {
      SetupRandomPalette();
      speed = 90;
      scale = 90;
      colorLoop = 1;
    }
    if (secondHand == 55) {
      currentPalette = RainbowStripeColors_p;
      speed = 30;
      scale = 20;
      colorLoop = 1;
    }
  }
}

// This function generates a random palette that's a gradient
// between four different colors.  The first is a dim hue, the second is
// a bright hue, the third is a bright pastel, and the last is
// another bright hue.  This gives some visual bright/dark variation
// which is more interesting than just a gradient of different hues.
void SetupRandomPalette() {
  currentPalette = CRGBPalette16(
    CHSV(random8(), 255, 32),
    CHSV(random8(), 255, 255),
    CHSV(random8(), 128, 255),
    CHSV(random8(), 255, 255));
}

// This function sets up a palette of black and white stripes,
// using code.  Since the palette is effectively an array of
// sixteen CRGB colors, the various fill_* functions can be used
// to set them up.
void SetupBlackAndWhiteStripedPalette() {
  // 'black out' all 16 palette entries...
  fill_solid(currentPalette, 16, CRGB::Black);
  // and set every fourth one to white.
  currentPalette[0] = CRGB::White;
  currentPalette[4] = CRGB::White;
  currentPalette[8] = CRGB::White;
  currentPalette[12] = CRGB::White;
}

// This function sets up a palette of purple and green stripes.
void SetupPurpleAndGreenPalette() {
  CRGB purple = CHSV(HUE_PURPLE, 255, 255);
  CRGB green = CHSV(HUE_GREEN, 255, 255);
  CRGB black = CRGB::Black;

  currentPalette = CRGBPalette16(
    green, green, black, black,
    purple, purple, black, black,
    green, green, black, black,
    purple, purple, black, black);
}


//
// Mark's xy coordinate mapping code.  See the XYMatrix for more information on it.
//
uint16_t XY(uint8_t x, uint8_t y) {
  uint16_t i;
  if (kMatrixSerpentineLayout == false) {
    i = (y * kMatrixWidth) + x;
  }
  if (kMatrixSerpentineLayout == true) {
    if (y & 0x01) {
      // Odd rows run backwards
      uint8_t reverseX = (kMatrixWidth - 1) - x;
      i = (y * kMatrixWidth) + reverseX;
    } else {
      // Even rows run forwards
      i = (y * kMatrixWidth) + x;
    }
  }
  return i;
}

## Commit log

2024-07-03 Rename Smart Irrigation System (Final practical application of the graduation project ) 🎓✨(720P_HD).mp4 to Smart Irrigation System (Final practical application of the graduation project ) 🎓✨.mp4
2024-07-03 Rename FlowChart - Copy.pdf to FlowChart.pdf
